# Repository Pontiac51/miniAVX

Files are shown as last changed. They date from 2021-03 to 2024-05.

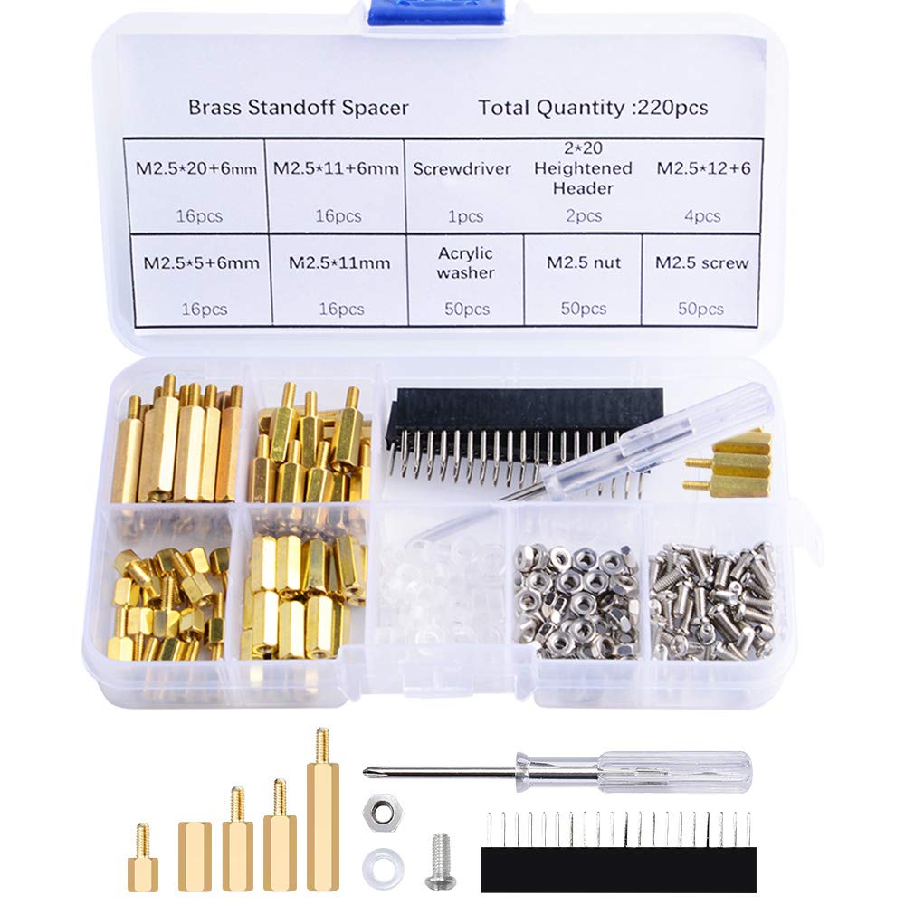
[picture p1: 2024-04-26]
Hardware/GeekPi M2.5 Standoff Kit.jpg

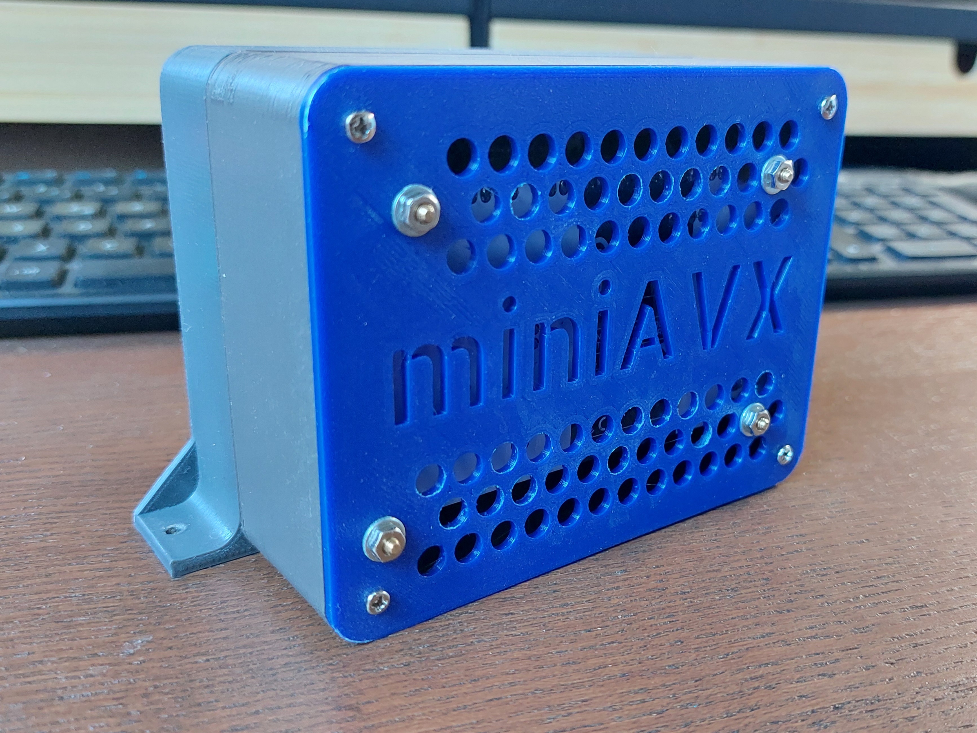
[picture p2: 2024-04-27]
STL/miniAVX-back.jpg

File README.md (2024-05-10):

# miniAVX 3.0.0 #

Mini Avionics Panel with Arduino for Microsoft Flight Simulator 2020 (MSFS)

***Functions:***
* Trim Elevator, Rudder & Aileron with display in %
* Display ALT (MSL, AGL), SPD (IAS (knts or Mach), GS) and QNH with adjustment knob
* Set and display HDG, OBS1 & 2
* Set and display autopilot values: ALT and V/S
* Set and display autopilot modes: Master, HDG, ALT, V/S, NAV, NAV/GPS switch
* Display direct course to next waypoint: -D>
* Complete Radio Stack: COM1 & 2, NAV1 & 2, ADF1 & 2, XPNDR1 (with mode & ident)
* Chronometer (Clock, Stopwatch and customizable Timer)
* Weather: Wind direction and speed (also in components), outside air temperature in C and F (in development)
* Adjust brightness and invert display

***Libraries used:***
* BitsAndDroids Connector - https://www.bitsanddroids.com/
* LedControl - https://www.arduinolibraries.info/libraries/led-control
* OLED_I2C - http://www.rinkydinkelectronics.com/library.php?id=79
* BigFont.c - Converted from RinkyDinkyElectronics, needs to go into OLED_I2C library folder

***ATTENTION!!!***
* BigFont.c and LedControl.h from "libraries" folder have to go into their respective libraries folder (OLED_I2C and LedControl/src) to make the OLED and 7-segment work properly!
* For the transponder mode to work custom events (Events -> Custom Output Settings) need to be created in BAD connector.

***Remarks:***
* The programer port is used for TX and the native port for RX. Reason is that a RX on programer port resets the Arduino.

***UPDATE 3.00.0 (BitsAndDroids NEW Rust Connector v0.3.7 & Library v1.6.9)***
* NEW: Weather module complete (with wind components and OAT in °C and °F)
* NEW: Transponder mode and ident INPUT
* NEW: Mach now also uses OAT for calculation
* FIXED: Groundspeed, temperature and wind speed calculation (rounding error)
* FIXED: Negative temperature display (double minus or no minus)
* FIXED: Windspeed displayed without leading zeros ("20" displayed as "020" or "2 ")

***UPDATE 2.27.1 (BitsAndDroids NEW Rust Connector v0.3.3 & Library v1.6.7)***
* NEW: Weather Demo (complete with wind components and temperatur in °C and °F)
* ADDED: Moved BigFont.c to its correct location and added the changed LedControl.h (with Backup) to have more letters (needed for wind components Head, Tail, Left, Right)
* UPDATED: Manual is now up to date!
* FIXED: On weather page when selecting "OAT" only OAT is shown

***UPDATE 2.26.0 (BitsAndDroids NEW Rust Connector v0.3.3 & Library v1.6.7)***
* NEW: Transponder IDENT (setting the mode in development)
* NEW: Weather menu entry (wind and temperature in development)
* NEW: Pages with progressbar! The menu now has 12 items which made scrolling to it a bit confusing. Reaching the last item on a page brings up the next page. Page title is also displayed in top left corner. Current pages: Essentials (Trim, Speed, Altitude, Chrono), Autopilot (ALT, VS, HDG, GPS, Transponder), Navigation (NAV, OBS, ADF) and Misc. (COM, WX, SET).
* ADDED: Switch "miniAVX version <-> BAD Version" on MAIN button on BRT INV page.
* REMOVED: Transponder 2 (has never been used in BAD or MSFS)

***UPDATE 2.25.0 (BitsAndDroids NEW Rust Connector 0.3.2 & Library v1.6.6)***
* FIXED: Brightness now changes OLED and LED in 15 steps.
* ADDED: STL files for 3D Printing
* ADDED: Github versioning

***UPDATE 2.21 (BitsAndDroids NEW Rust Connector 0.2.18 & Library v1.6.6)***
* FIXED: AP VS values are now displayed properly.

***UPDATE 2.20 (BitsAndDroids NEW Rust Connector 0.2.16 & Library v1.6.5)***
* NEW: Display of Transponder Mode (Off, Stby, On, Alt, Grnd, Test if applicable)
* NEW: Display of IAS in Mach (Turn left knob in IAS mode to switch)
* CHANGED: Shifted SPD page display on LED one to the left. Thx to fjbermejillo for the hint!
* CHANGED: ADFs now displayed with Hz digit
* FIXED: ADFs not displayed correctly if 4 digits.
* BUG: AP VS values are not displayed properly, setting works!

***UPDATE 2.17.163 (BitsAndDroids NEW Rust Connector 0.2.14 & Library v1.6.3)***
* NEW: Clock with Local and Zulu time, stopwatch and customizable timer
* BUG: ADFs not displayed correctly if 4 digits.

***UPDATE 2.02.178 (BitsAndDroids Library v1.6.0 & Connector 1.7.8)***
* CHANGED "GPS" to "-D>" as it now displays direct heading to next waypoint of flightplan (button press is still GPS-NAV switch)
* CHANGED If the aircraft is on the ground altitude AGL is displayed as 0
* FIXED Kohlsman HG reading incorrectly (29 instead of 29.92)

***UPDATE 2.01.160 (BitsAndDroids v1.6.0)***
* CHANGED If Autopilot V/S is OFF "----" will be displayed
* FIXED Display NAV Standby Frequencies not working
* FIXED Display Autopilot V/S Mode Display not working

***UPDATE 2.00.160 (BitsAndDroids v1.6.0)***
* NEW: Debounced buttons & handled rotary decoder via interrupts for better performance (especially on fast movements
* CHANGED Removed AP Modes from OLED (had snyc issues), still available in digit display
* BUG Display NAV Standby Frequencies not working (have to check)
* BUG Autopilot V/S Mode Display not working (have to check)
* BUG Auotpilot GPS Mode Display not working (not implemented)

***UPDATE 1.92.090 (BitsAndDroids v0.9.0)***
* NEW AP Master ON/OFF on main switch in pages "HDG GPS", "ALT V/S" and "OBS"
* NEW Active AP modes are now shown on "HDG GPS", "ALT V/S" and "OBS" pages with a vertical stripe ("|")
* NEW Rudder and aileron trim now feature coarse mode
* CHANGED Main button clockwise turn is now down in main menu, counter-clockwise is up
* CHANGED "NAV" and "COM" pages now display "STBY"
* CHANGED "ELE" to "ELV" on trim page
* CHANGED "OBS1-2" to "OBS  1-2" to allow to disply active AP NAV mode
* CHANGED order of menu items to fit with "Aviate-Navigate-Communicate"

***UPDATE 1.91.088 (BitsAndDroids v0.8.8)***
* CHANGED COM, NAV split to seperate draw functions on the digit display (different frequency formats)
* CHANGED Redraw interval from 100ms to 50ms
* FIXED Renamed "VS" to "V/S"
* FIXED ADF, XPDNR 

***UPDATE 1.90.087 (BitsAndDroids v0.8.7)***
* NEW BIG font for menu items (BigFont.c; ADD to OLED_I2C library)
* NEW Selected item now shown inverted, Cursor ">" removed
* NEW Version number now shows BAD version as well
* CHANGED Altitude can now be switched between MSL and AGL with main button independently
* CHANGED Speed can now be switched between IAS and GS with left button independently
* CHANGED QNH can now be switched ON/OFF with right button on SPD-ALT page
* CHANGED Redesign of UI for better readability

***UPDATE 1.87 (BitsAndDroids v0.8.7)***
* NEW TRIM percentages for elevator, aileron and rudder, main button switches elevator and aileron
* NEW Elevator trim has coarse/fine setting (turn slowly on coarse); left button to switch (. means coarse)
* NEW Autopilot Master ON is displayed with an "A" on HDG page (no function to switch OFF/ON, display only)
* NEW VS -1000 and above display a thousands seperator, e.g. VS at -1200 feet would read as "-1.20"
* NEW All autopilot modes display a dot after the last digit, e.g. HDG "350." means HDG autopilot is active
* CHANGED Menu order: TRIM - ALT/SPD - Autopilot (HDG, GPS, ALT, VS, OBS) - Radio (COM, NAV, ADF, XPNDR)
* CHANGED Moved baro setting to ALT - SPD page, press left button to show QNH
* CHANGED Moved GPS course to HDG page
* FIXED Renamed ALTs and SPDs to proper abbreviations

***UPDATE 1.06 (BitsAndDroids v0.8.4)***
* OBS 1 & 2 display now working
* GPS course display
* NAV1 and GPS Autopilot ON/OFF (NAV1 mode press OBS1, GPS mode press GPS)
* ALT and SPD can be switched between radar/indicated and indicated/ground

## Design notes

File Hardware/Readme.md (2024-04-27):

All hardware related information, like pictures of used hardware and the schematics.

***Material List:***

* 1x Arduino Due
* 3x Rotary encoder with pushbutton (KY-040 or similar)
* 1x OLED I2C Display 128x64 (monochrome)
* 1x 8-Digit seven segment display with MAX7219 IC
* Breadboard Cables
* Housing (see folder "STL" for 3D printing files)
* Standoff Kit (see Picture)

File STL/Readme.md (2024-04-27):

Case STL files for 3D Printing 

* Printed on Ender5pro
* PLA from 3DJake and Formfutura

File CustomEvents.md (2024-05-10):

ID		Action								            Description
1002	0 (>A:TRANSPONDER STATE:1, enum)	Transponder state off
1003	1 (>A:TRANSPONDER STATE:1, enum)	Transponder state standby
1004	2 (>A:TRANSPONDER STATE:1, enum)	Transponder state test
1005	3 (>A:TRANSPONDER STATE:1, enum)	Transponder state on
1006	4 (>A:TRANSPONDER STATE:1, enum)	Transponder state alt
1007	5 (>A:TRANSPONDER STATE:1, enum)	Transponder state ground

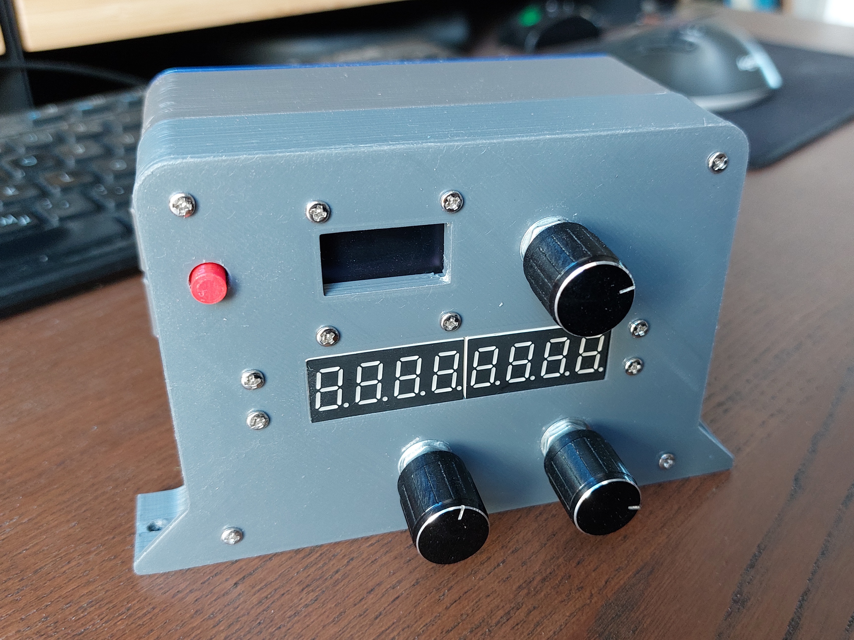
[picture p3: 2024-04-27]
STL/miniAVX-front.jpg

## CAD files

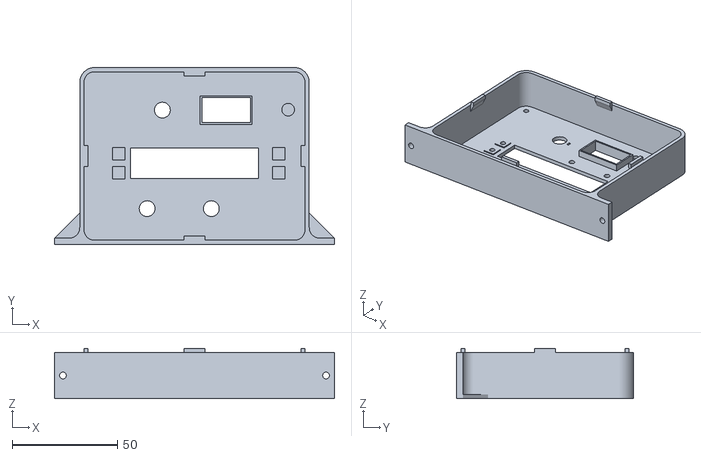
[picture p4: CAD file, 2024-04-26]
STL/miniAVX - Front.stl
133.0 x 84.0 x 23.9

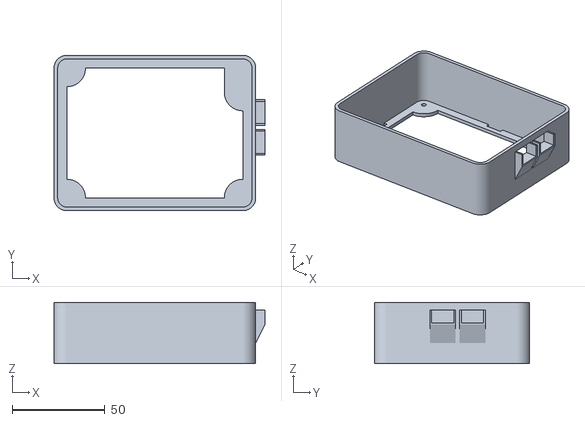
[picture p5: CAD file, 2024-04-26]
STL/miniAVX - Middle.stl
114.0 x 84.0 x 33.0

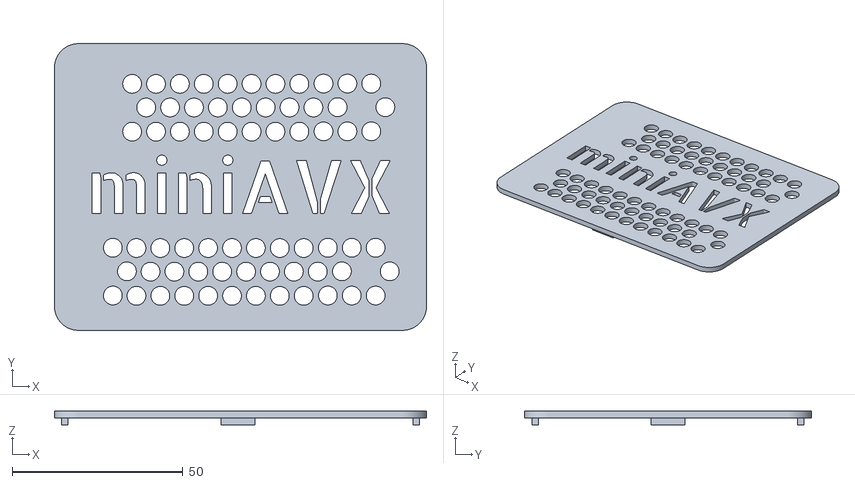
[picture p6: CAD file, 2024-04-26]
STL/miniAVX - Back.stl
109.0 x 84.0 x 4.00

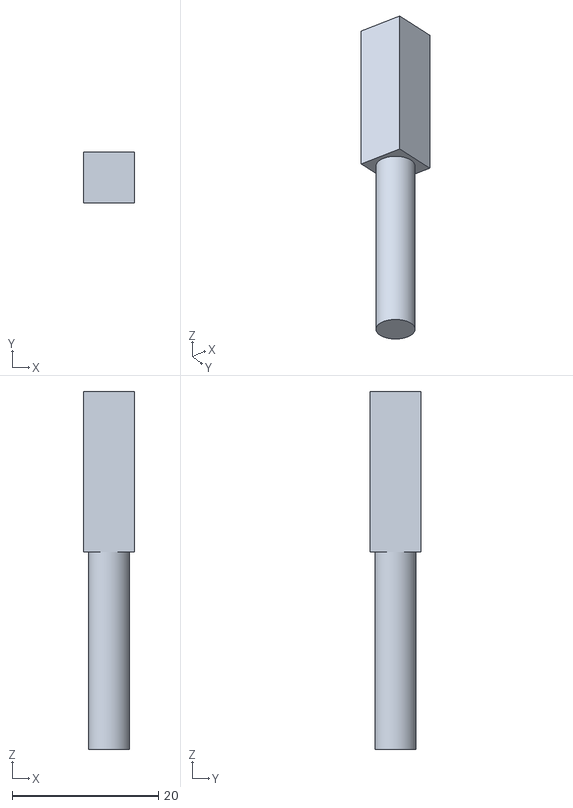
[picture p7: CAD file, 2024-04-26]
STL/miniAVX - Reset.stl
7.00 x 7.00 x 49.0

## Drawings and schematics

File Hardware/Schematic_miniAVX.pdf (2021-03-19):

USB | SPI GND GND@⁶

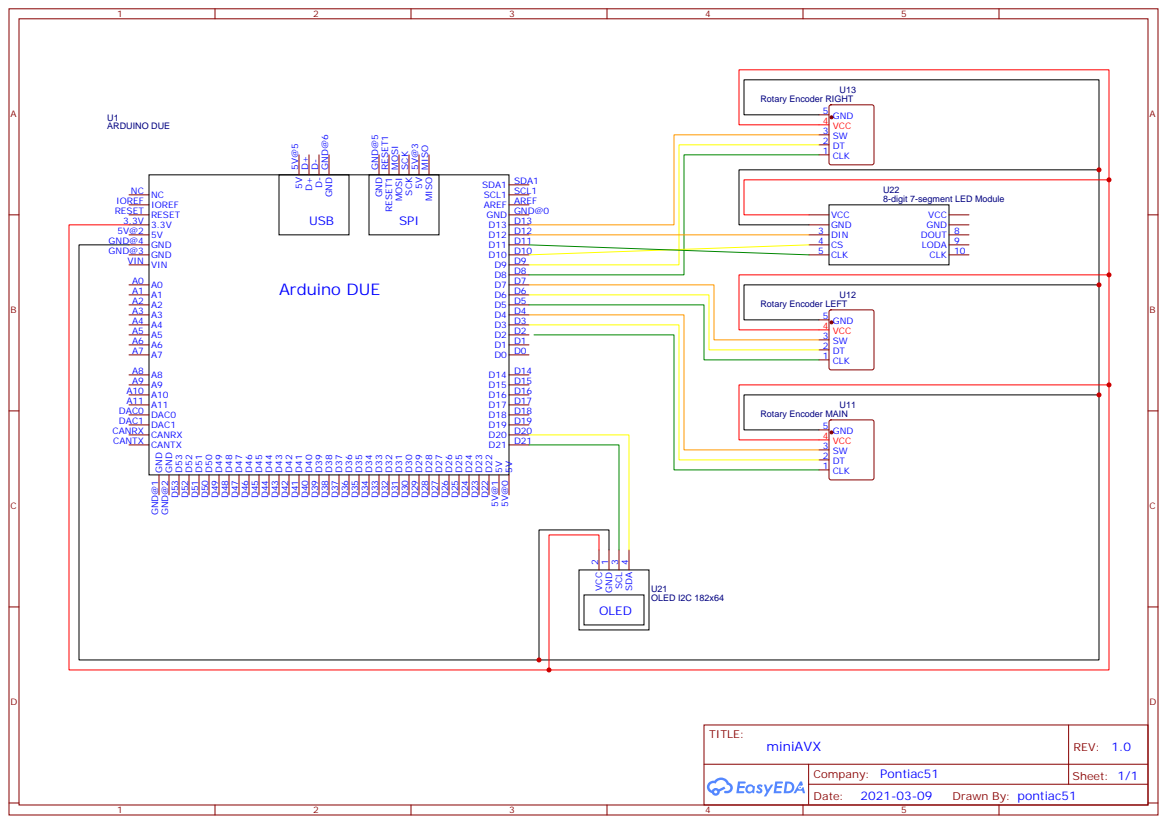
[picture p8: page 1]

SCK SCK MOSI MOSI

8-digit 7-segment LED Module

D21 D21 D²² D²² D²³ D²³ D²⁴ D²⁴ D²⁵ D²⁵ D²⁶ D²⁶ D²⁷ D²⁷ D²⁸ D²⁸

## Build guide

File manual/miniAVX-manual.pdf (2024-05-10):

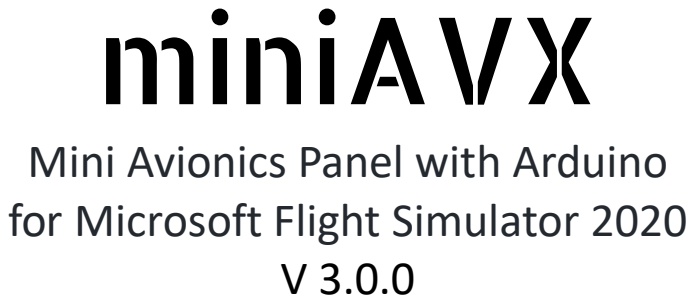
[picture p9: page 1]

# miniAVX

## Mini Avionics Panel with Arduino for Microsoft Flight Simulator 2020

V 3.0.0

# Trim: Elevator, Rudder and Aileron

Scroll Down

Scroll Up

Rudder ↔ Aileron

Elevator Up

Elevator Down

Rudder/Aileron Right

Rudder/Aileron Left

# Basic Avionics: Speed, Height and QNH

Scroll Down

Scroll Up

MSL ↔ AGL

QNH +

QNH -

Knots ↔ Mach

Knots ↔ Mach

IAS ↔ GS | ALT ↔ QNH

# Chronograph: Clock, Stopwatch and Timer

Scroll Down

Scroll Up

Stopwatch ↔ Timer

Timer Minutes +

Timer Seconds -

Local ↔ Zulu | Start, Stop, Reset

# Autopilot: Height and Vertical Speed

Scroll Down

Scroll Up

AP Master ON/OFF

AP ALT +

AP ALT -

AP V/S +

AP V/S -

AP ALT ON/OFF | AP V/S ON/OFF

# Autopilot: Heading and GPS Course

Scroll Down

Scroll Up

AP Master ON/OFF

HDG Bug +

HDG Bug -

AP HDG ON/OFF | AP GPS/NAV Toggle

# Radio: Transponder

Scroll Down

Scroll Up

XPNDR +

XPNDR -

Switch Mode +

Switch Mode -

Switch Digit | Ident

# Autopilot: Omni Bearing Selector (OBS)

Scroll Down

Scroll Up

AP Master ON/OFF

OBS1 Course +

OBS1 Course -

OBS2 Course +

OBS2 Course -

AP NAV1 ON/OFF

# Radio: NAV

Scroll Down

Scroll Up

NAV1 <-> NAV2

Mhz +

Mhz -

Khz +

Khz -

Standby <-> Active | Standby <-> Active

# Radio: ADF

Scroll Down

Scroll Up

ADF1 ↔ ADF2

ADF Khz +

ADF Khz -

ADF Hz +

ADF Hz -

Switch Digit

# Radio: COM

Scroll Down

Scroll Up

COM1 <-> COM2

Mhz +

Mhz -

Khz +

Khz -

Standby <-> Active | Standby <-> Active

# Weather: Wind and OAT

Wind Speed ↔ OAT

Wind Components | OAT °C ↔ °F

Scroll Down

Scroll Up

# Settings

Scroll Down

Scroll Up

Brightness +

Brightness -

Invert

Ver: miniAVX ↔ BAD

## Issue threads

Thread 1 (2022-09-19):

Bug Report, Suggestions

Pontiac51, 2022-09-19:
Bug: ADF2 wrong by a digit, should show 1400 but shows 0140
Bug: "ELE" should read "ELV"
Bug: Main menu: CW turn is down, CCW turn is up
Feature: Coarse mode for aileron and rudder trim
Feature: Show finer trim pct, 0.1 or steps
Feature: Show active AP modes on OLED (space in the middle)
Feature: Implement Autopilot Master Switch
Feature: Add "STBY" to COM and NAV on OLED

Pontiac51, 2022-09-20:
BUG: ADF: Code is the same for ADF1 and ADF2, have to check input from MSFS
BUG: Changed "ELE" to "ELV"
BUG: Main Menu fixed (CW is down, CCW is up)
FEATURE: "STBY" added to COM and NAV on OLED
FEATURE: Coarse Mode added for rudder and aileron trim

Omitted:
FEATURE: Show finer trim pct: Not possible, MSFS only delivers whole percent

Pontiac51, 2022-09-20:
FEATURE: On "HDG  GPS" page, main button turns ON/OFF AP Master.
FEATURE: Active AP Modes (HDG, GPS, ALT, V/S) are now shown with a "|" in OLED screen

Closed 2022-09-20.

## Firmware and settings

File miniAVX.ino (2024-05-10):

#include <LedControl.h>
#include <BitsAndDroidsFlightConnector.h>
#include <LedControl.h>
#include <OLED_I2C.h>

#define ARDUINO_SAM_DUE

String MAJOR = "3";
String MINOR = "0";
String PATCH = "0";
String version = MAJOR + "." + MINOR + "." + PATCH;
String BADConnector = "0.3.7"; // this is the new RUST app (04/2024)
String BADLibrary = "1.6.9";
String BADVersion = BADConnector + "|" + BADLibrary;



//data type for button
struct Button {
  uint8_t gpioSw;
  uint8_t lastStateSw;
};

//data type for rotary
struct Rotary {
  int rotationCounter;
  uint8_t gpioClk;
  uint8_t gpioDt;
  volatile bool rotMoved;
  Button button;
};

#define ROTARIES 3
Rotary rotaries[ROTARIES];

// debouncing - used on buttons only (not rotaries)
unsigned long lastSample = 0;
int debounce = 5; // time in ms

//BAD - true for pro-micro / Leonardo
BitsAndDroidsFlightConnector connectorTX(&Serial);
BitsAndDroidsFlightConnector connectorRX(&SerialUSB);

//data tpye for menu item
struct menuItem {
  String entry;
  boolean option = false; 
  void (*onSelect)();
  void (*drawLED)(); 
};

// Init Menu Structure
#define MAX_ITEMS 20
menuItem itemsMain[MAX_ITEMS];
uint8_t mainMenuLength = 0;
int menu = 0;
int firstItem = 0;
int selItem = 0;

// set where page are in list
int idxApHdgGps = 3;
int idxApAltVs = 2;
int idxApObs = 4;

// Init Cursor
int yArr[] = {16, 32, 48}; // 3 mneu items
int iArr = 0;
int page = 0;
String pageArr[] = {"| ESS  |", "|  AP  |", "| NAV  |", "| MISC |"};

// Init ADF
int adfDigit = 2;

// Init XPNDR
int xpndrDigit = 3;

//Init ALT page
boolean showBaro = false;
String pageALT = "MSL";

//Init SPD page
boolean showGS = false;
boolean showIAS = true;
String pageSPD = "IAS";

//Init CLK page
boolean showZ = false;
// Stopwatch (counting up)
long millisStartStw = 0;
long millisStw = 0;
int currStateStw = 0; // 0 = Reset, 1 = Start (running), 2 = Stop

// Timer (counting down)
long milTmrStart = 0; // start time of timer in millis
long milTmrSpan = 0;  // preset run time of timer in millis
long milTmrDisp = 0;  // time to show
int minsTmr = 0;
int secsTmr = 0;
int currStateTmr = 0; // 0 = Reset, 1 = Start (running), 2 = Stop

// Weather
boolean showOATFahrenheid = false;
boolean showWindPerp = false;

// constructor for menu item
void addMenuItem(String entry, void (*onSelect)()) {
    if (mainMenuLength >= MAX_ITEMS) return;
    itemsMain[mainMenuLength].entry = entry;
    itemsMain[mainMenuLength].onSelect = onSelect;
    mainMenuLength++;
}

// constructor for menu item callback
void (*onMainSelect)();
void (*onLeftSelect)();
void (*onLeftCW)();
void (*onLeftCCW)();
void (*onRightSelect)();
void (*onRightCW)();
void (*onRightCCW)();
void (*drawLED)();

// Interrupt routines
void rotaryMain()
{
  rotaries[0].rotationCounter += checkRotaryEncoder(&rotaries[0]);
}
void rotaryLeft()
{
  rotaries[1].rotationCounter += checkRotaryEncoder(&rotaries[1]);
}
void rotaryRight()
{
  rotaries[2].rotationCounter += checkRotaryEncoder(&rotaries[2]);
}

// Rotary encoder has moved (interrupt tells us) but what happened?
// See https://www.pinteric.com/rotary.html
int8_t checkRotaryEncoder(Rotary *cur)
{
    // Reset the flag that brought us here (from ISR)
    cur->rotMoved = false;

    static uint8_t lrmem = 3;
    static int lrsum = 0;
    static int8_t TRANS[] = {0, -1, 1, 14, 1, 0, 14, -1, -1, 14, 0, 1, 14, 1, -1, 0};

    // Read BOTH pin states to deterimine validity of rotation (ie not just switch bounce)
    int8_t l = digitalRead(cur->gpioClk);
    int8_t r = digitalRead(cur->gpioDt);

    // Move previous value 2 bits to the left and add in our new values
    lrmem = ((lrmem & 0x03) << 2) + 2 * l + r;

    // Convert the bit pattern to a movement indicator (14 = impossible, ie switch bounce)
    lrsum += TRANS[lrmem];

    // encoder not in the neutral (detent) state
    if (lrsum % 4 != 0)
    {
        return 0;
    }
    // encoder in the neutral state - clockwise rotation
    if (lrsum == 4)
    {
        lrsum = 0;
        return 1;
    }
    // encoder in the neutral state - anti-clockwise rotation
    if (lrsum == -4)
    {
        lrsum = 0;
        return -1;
    }
    // An impossible rotation has been detected - ignore the movement
    lrsum = 0;
    return 0;
}

// define OLED
OLED myOLED(SDA, SCL);
extern uint8_t TinyFont[];
extern uint8_t SmallFont[];
extern uint8_t BigFont[];
int OLEDbright = 17;
boolean inverted = false;
boolean showBADversion = false;

// define 7-segment display
#define REDRAW_INTERVAL 50
long lastRedraw = 0;
LedControl lc=LedControl(12,11,10,1);
int LCDbright = 1;

void setupRotary(Rotary *cur, uint8_t gpioClk, uint8_t gpioDt , uint8_t gpioSw) {
  cur->rotationCounter = 0;
  cur->gpioClk = gpioClk;
  cur->gpioDt = gpioDt;
  cur->rotMoved = false;
  cur->button.gpioSw = gpioSw;
  cur->button.lastStateSw = LOW;
  
  // The module already has pullup resistors on board
  pinMode(cur->gpioClk, INPUT);
  pinMode(cur->gpioDt, INPUT);

  // But not for the push switch
  pinMode(cur->button.gpioSw, INPUT_PULLUP);
}

void setup() {
  // menu - first item is 0
  // menu create by aviate - navigate - communicate
  addMenuItem("ELV  RUD", &onTrimSelect);
  addMenuItem(pageSPD + "  " + pageALT, &onAltSpeedSelect);
  addMenuItem("CLK  STW", &onClkStwSelect);
  addMenuItem("ALT  V/S", &onAltVsSelect);
  addMenuItem("HDG  -D>", &onHdgGPSSelect);
  addMenuItem("XPNDR   ", &onXpndrSelect);
  addMenuItem("NAV1 Sby", &onNavSelect);
  addMenuItem("OBS  1-2", &onOBSSelect);
  addMenuItem("ADF1 Sby", &onAdfSelect);
  addMenuItem("COM1 Sby", &onComSelect);
  addMenuItem("WX   WND", &onWxSelect); 
  addMenuItem("BRT  INV", &onBrightInvSelect);

  // Init OLED
  myOLED.begin(); 
  myOLED.clrScr();  
  myOLED.setFont(SmallFont);
  myOLED.setBrightness(OLEDbright);
  displayOLEDtitle();
  myOLED.print("Loading", 0, yArr[0]);
  myOLED.update();

  //Init LCD
  delay(1000);
  lc.shutdown(0,false);
  lc.setIntensity(0,LCDbright);
  for(int i = 0; i <= 7; i++){
    lc.setChar(0,i,8,true);
  }

  // rotaries
  setupRotary(&rotaries[0], 2, 3, 4);
  attachInterrupt(digitalPinToInterrupt(2), rotaryMain, CHANGE);
  attachInterrupt(digitalPinToInterrupt(3), rotaryMain, CHANGE); 
  setupRotary(&rotaries[1], 5, 6, 7);
  attachInterrupt(digitalPinToInterrupt(5), rotaryLeft, CHANGE);
  attachInterrupt(digitalPinToInterrupt(6), rotaryLeft, CHANGE); 
  setupRotary(&rotaries[2], 8, 9, 13);
  attachInterrupt(digitalPinToInterrupt(8), rotaryRight, CHANGE);
  attachInterrupt(digitalPinToInterrupt(9), rotaryRight, CHANGE); 
  
  // Init START PAGE
  delay(1000);
  lc.clearDisplay(0);
  scrollLED();
  pressAll3Buttons(); // Fix for bug of all 3 buttons pressed on init.
  updateOLED();

  //Open USB port
  //If you're using a Leonardo / Pro-micro this line can be left out.
  Serial.begin(115200);
  SerialUSB.begin(115200);
   //If you notice some instability gradually increase this value with increments of 5.
  SerialUSB.setTimeout(15); 
  Serial.setTimeout(15);
}

void loop() {
  connectorRX.dataHandling();
  redrawLED();
  loopRotaries();
}

void updateOLED(){
  displayOLEDMain();
}

void displayOLEDMain(){
  int x = firstItem+1 % mainMenuLength;
  int y = firstItem+2 % mainMenuLength;
  int z = firstItem+3 % mainMenuLength;
  int pageX = 0;
  int pageY = pageX + 31;
  myOLED.clrScr();
  displayOLEDtitle();
  switch (page){
    case 0:
    pageX = 0;
    break;
    case 1:
    pageX = 32;
    break;
    case 2:
    pageX = 64;
    break;
    case 3:
    pageX = 96;
    break;
  }
  pageY = pageX + 31;
  //myOLED.drawLine(pageX,10,pageY,10);
  myOLED.drawRect(pageX, 10, pageY, 13);
  myOLED.drawRect(pageX, 11, pageY, 12);
  invSelected(x, 0, iArr);
  invSelected(y, 1, iArr);
  invSelected(z, 2, iArr);      
  myOLED.update();
}

// version MIDDLE, page RIGHT
/*
void displayOLEDtitle(){
  // myOLED.drawRoundRect(0,0,127,10);
  // myOLED.drawLine(0,14,127,14);
  myOLED.setFont(SmallFont);
  myOLED.print("miniAVX " + version, LEFT, 0);
  //myOLED.setFont(TinyFont);
  if (!showBADversion){
    myOLED.print(pageArr[page], RIGHT, 0);
  } else {
    myOLED.print(removePeriodAndZero(BADVersion), RIGHT, 0);
  }
  myOLED.setFont(BigFont);
}
*/

// version RIGHT, page MIDDLE
void displayOLEDtitle(){
  myOLED.drawRect(3, 6, 45, 10);
  myOLED.drawRect(0, 10, 127, 14);
  myOLED.setFont(SmallFont);
  myOLED.print(pageArr[page], LEFT, 0);
  //myOLED.setFont(TinyFont);
  if (!showBADversion){
    myOLED.print("miniAVX " + removePeriodAndZero(version), RIGHT, 0);
  } else {
    myOLED.print("BAD " + removePeriodAndZero(BADVersion), RIGHT, 0);
  }
  myOLED.setFont(BigFont);
}

void invSelected(int iItem, int itemArr, int cursorArr){
  // iItem: menu item
  // itemArr: index of item
  // cursorArr: index of cursor
  if (itemArr == cursorArr){
    myOLED.invertText(true);
    myOLED.print(itemsMain[iItem-1].entry, 0, yArr[itemArr]);
    myOLED.invertText(false);
  } else {
    myOLED.print(itemsMain[iItem-1].entry, 0, yArr[itemArr]);
  }
}

void loopRotaries() {
  Rotary *cur;
  for (int i = 0; i < ROTARIES; i++) {
    cur = &rotaries[i];
    // first, check state
    int currentStateSw = digitalRead(cur->button.gpioSw);      
    // If valid movement, do something
    while(cur->rotationCounter != 0)
    {
      if(cur->rotationCounter > 0) {
        // turned clockwise
        cur->rotationCounter--;
        switch(i){
          case 0: //MAIN
          mainDown();
          break;
          case 1: //LEFT
          if(onLeftCW != NULL) onLeftCW();
          break;
          case 2: //RIGHT
          if(onRightCW != NULL) onRightCW();
          break;
          default:
          break;
        }
      } else {
        // turned counter-clockwise
        cur->rotationCounter++;
        switch(i){
          case 0: //MAIN
          mainUp();
          break;
          case 1: //LEFT
          if(onLeftCCW != NULL) onLeftCCW();
          break;
          case 2: //RIGHT
          if(onRightCCW != NULL) onRightCCW();
          break;
          default:
          break;
        }            
      }
    }
    if (currentStateSw != cur->button.lastStateSw && currentStateSw == HIGH) {
      switch(i){
        case 0: //MAIN
        if(onMainSelect != NULL) onMainSelect();
        break;
        case 1: //LEFT
        if(onLeftSelect != NULL) onLeftSelect();
        break;
        case 2: //RIGHT
        if(onRightSelect != NULL) onRightSelect();
        break;
        default:
        break;
      } 
    }
    cur->button.lastStateSw = currentStateSw;
    delay(debounce); 
  }
}

void scrollLED(){
  if (selItem >= 0 && selItem < mainMenuLength && itemsMain[selItem].onSelect != NULL) itemsMain[selItem].onSelect();
}

void pressAll3Buttons(){
  if (selItem >= 0 && selItem < mainMenuLength && itemsMain[selItem].onSelect != NULL){
    if(onMainSelect != NULL) onMainSelect();
    if(onLeftSelect != NULL) onLeftSelect();
    if(onRightSelect != NULL) onRightSelect();
  }
}

String removePeriodAndZero(String inputString) {
    // Remove all periods (.)
    inputString.replace(".", "");
    // Remove all zeros (0)
    inputString.replace("0", "");
    
    // Return the modified string
    return inputString;
}

// Function to convert degrees to radians
float degreesToRadians(float degrees) {
    return degrees * (PI / 180.0);
}

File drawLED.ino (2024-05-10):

void drawLEDAltSpd(){
  int alt = 0;
  float spd = 0;
  if (!showBaro){
    if (!itemsMain[selItem].option){ // MSL    
      alt = connectorRX.getIndicatedAltitude();
    } else { // AGL
      if (!connectorRX.getOnGround()){
        alt = connectorRX.getFeetAboveGround();
      } else {
        alt = 0;
      }
    }
  } else {
    alt = connectorRX.getKohlmanAltimeter();
  }    
  if (!showGS){ 
    // show IAS or Mach
    spd = connectorRX.getIndicatedAirspeed();
    if (!showIAS || spd > 999){
      float tempK = connectorRX.getAmbientTemperature() + 273.15;
      spd = spd / (1.94384 * sqrt(1.4 * 287.05 * tempK));
    }
  } else {
    // show Groundspeed
    spd = connectorRX.getIndicatedGPSGroundspeed();
  }
  if (!showIAS && !showGS){
    spd = round(spd * 100);
    lc.setChar(0,7,(int(spd)/100)%10,true);
    lc.setChar(0,6,(int(spd)/10)%10,false);
    lc.setChar(0,5,int(spd)%10,false);
    lc.setChar(0,4,' ',false);
  } else {
    lc.setChar(0,7,(round(spd)/100)%10,false);
    lc.setChar(0,6,(round(spd)/10)%10,false);
    lc.setChar(0,5,round(spd)%10,false);
    lc.setChar(0,4,' ',false);
  }    
  if (alt < 10000){
    lc.setChar(0,3,(alt/1000)%10,false);
    if (!showBaro){
      lc.setChar(0,2,(alt/100)%10,false);
    } else { // decimal point for barometer
      lc.setChar(0,2,(alt/100)%10,true);
    }
    lc.setChar(0,1,(alt/10)%10,false);
    lc.setChar(0,0,alt%10,false);
  } else {    
    lc.setChar(0,3,'F',false);
    lc.setChar(0,2,(alt/10000)%10,false);
    lc.setChar(0,1,(alt/1000)%10,false);
    lc.setChar(0,0,(alt/100)%10,false);
  } 
}

void drawLEDHdgGPS(){
  int hdg = connectorRX.getApHeadingLock();
  int gps = connectorRX.getGpsCourseToSteer();
  if(!connectorRX.getAPMasterOn()){
    lc.setChar(0,7,' ',false);
  } else {
    lc.setChar(0,7,'A',false);
  }
  lc.setChar(0,6,(hdg/100)%10,false);
  lc.setChar(0,5,(hdg/10)%10,false);
  lc.setChar(0,4,hdg%10,connectorRX.getAPHeadingLockOn());
  lc.setChar(0,3,' ',false);
  lc.setChar(0,2,(gps/100)%10,false);
  lc.setChar(0,1,(gps/10)%10,false);
  lc.setChar(0,0,gps%10,false);    
}

void drawLEDCom(){
  if (!itemsMain[selItem].option){ // 1
    displayLEDfreqCOM(connectorRX.getStandbyCom1());
  } else { // 2
    displayLEDfreqCOM(connectorRX.getStandbyCom2());
  }
}

void drawLEDNav(){
    if (!itemsMain[selItem].option){ // 1
      displayLEDfreqNAV(connectorRX.getStandbyNav1());
    } else { // 2
      displayLEDfreqNAV(connectorRX.getStandbyNav2());
    }
}

void displayLEDfreqCOM(long freq){
  lc.setChar(0,7,' ',false);
  lc.setChar(0,6,(freq/100000)%10,false);
  lc.setChar(0,5,(freq/10000)%10,false);
  lc.setChar(0,4,(freq/1000)%10,true);
  lc.setChar(0,3,(freq/100)%10,false);
  lc.setChar(0,2,(freq/10)%10,false);
  lc.setChar(0,1,freq%10,false);
  lc.setChar(0,0,' ',false);
}

void displayLEDfreqNAV(long freq){
  lc.setChar(0,7,' ',false);
  lc.setChar(0,6,(freq/100000)%10,false);
  lc.setChar(0,5,(freq/10000)%10,false);
  lc.setChar(0,4,(freq/1000)%10,true);
  lc.setChar(0,3,(freq/100)%10,false);
  lc.setChar(0,2,(freq/10)%10,false);
  lc.setChar(0,1,freq%10,false);
  lc.setChar(0,0,' ',false);
}

void drawLEDObs(){
  int obs1 = connectorRX.getNavObs1();
  int obs2 = connectorRX.getNavObs2();
  lc.setChar(0,7,' ',false);
  lc.setChar(0,6,(obs1/100)%10,false);
  lc.setChar(0,5,(obs1/10)%10,false);
  lc.setChar(0,4,obs1%10,connectorRX.getAPNav1LockOn());
  lc.setChar(0,3,' ',false);
  lc.setChar(0,2,(obs2/100)%10,false);
  lc.setChar(0,1,(obs2/10)%10,false);
  lc.setChar(0,0,obs2%10,false);  
}

void drawLEDAdf(){
  long adf = 0;
  if (!itemsMain[selItem].option){ // 1
    adf = connectorRX.getAdfStandbyFreq1();
  } else { // 2
    adf = connectorRX.getAdfStandbyFreq2();
  }
  if (((adf/10000)%10) != 0){
    lc.setChar(0,7,(adf/10000)%10,false);
  } else {
    lc.setChar(0,7,' ',false);
  }
  lc.setChar(0,6,(adf/1000)%10,false);
  lc.setChar(0,5,(adf/100)%10,false);
  lc.setChar(0,4,(adf/10)%10,false);

  switch (adfDigit){
    case 0: 
    break;
    case 1:
    lc.setChar(0,5,(adf/100)%10,true);
    break;
    case 2:
    lc.setChar(0,6,(adf/1000)%10,true);
    break;
    default:
    break;
  }
  lc.setChar(0,4,(adf/10)%10,true);
  lc.setChar(0,3,adf%10,false);
  lc.setChar(0,2,' ',false);
  lc.setChar(0,1,' ',false);
  lc.setChar(0,0,' ',false); 
}

void drawLEDXpndr(){
  long xpndr = 0;
  int state = 0;
  boolean ident = false;
  String mode = "----";
  // removed as transponder 2 not used by BAD or MSFS
  /*
  if (!itemsMain[selItem].option){ // 1
    xpndr = connectorRX.getTransponderCode1().toInt();
    state = connectorRX.getTransponderState1();
    ident = connectorRX.getTransponderIdent1();
  } else { // 2
    xpndr = connectorRX.getTransponderCode2().toInt();
    state = connectorRX.getTransponderState2();
    ident = connectorRX.getTransponderIdent2();
  }
  */
  xpndr = connectorRX.getTransponderCode1().toInt();
  state = connectorRX.getTransponderState1();
  ident = connectorRX.getTransponderIdent1();

  lc.setChar(0,7,(xpndr/1000)%10,false);
  lc.setChar(0,6,(xpndr/100)%10,false);
  lc.setChar(0,5,(xpndr/10)%10,false);
  lc.setChar(0,4,xpndr%10,false); 
  switch (xpndrDigit){
    case 0:
    lc.setChar(0,4,xpndr%10,true); 
    break;
    case 1:
    lc.setChar(0,5,(xpndr/10)%10,true);
    break;
    case 2:
    lc.setChar(0,6,(xpndr/100)%10,true);
    break;
    case 3:
    lc.setChar(0,7,(xpndr/1000)%10,true);
    break;
    default:
    break;
  }

  if (!ident){
    switch (state){
      case 0:
      mode = " 0FF";
      break;
      case 1:
      mode = " 5by";
      break;
      case 2:
      mode = " t5t";
      break;
      case 3:
      mode = " 0n ";
      break;
      case 4:
      mode = " ALt";
      break;
      case 5:
      mode = " 6nd";
      break;
      default:
      break;
    }
  } else {
    mode ="1dnt";
  }
  lc.setChar(0,3,mode.charAt(0),false);
  lc.setChar(0,2,mode.charAt(1),false);
  lc.setChar(0,1,mode.charAt(2),false);
  lc.setChar(0,0,mode.charAt(3),false);
}

void drawLEDBrightInv(){
  char inv[4] = {' ',' ',' '};
  if (inverted){
    inv[0] = 0; inv[1] = 'n'; inv[2] = ' ';
  } else {
    inv[0] = 0; inv[1] = 'F'; inv[2] = 'F';
  }  
  lc.setChar(0,7,'B',false);
  lc.setChar(0,6,' ',false);
  lc.setChar(0,5,(LCDbright/10)%10,false);
  lc.setChar(0,4,LCDbright%10,false);
  lc.setChar(0,3,' ',false);
  lc.setChar(0,2,inv[0],false);
  lc.setChar(0,1,inv[1],false);
  lc.setChar(0,0,inv[2],false);
  //delay(1);   
}
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

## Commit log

2023-11-22 Update miniavx.ino
    Changed to Interrupts
    Update to BAD 1.6.0
2024-04-27 Folder structure added
    [miniAVX - Back.stl, miniAVX - Front.stl, miniAVX - Middle.stl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]
2024-04-29 v.2.27.1
    fixed weather page to show only OAT when selected, updated manual
    [drawLED.ino, miniAVX.ino, onInput.ino]
